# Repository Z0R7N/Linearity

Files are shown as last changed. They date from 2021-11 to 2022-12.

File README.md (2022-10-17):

# Linearity
 check linearity for device with arduino, excel and VBA
 проверка линейности с ардуино и надстройкой к екселю на VBA

panel

The add-on via the COM port, using the API written by me, sends commands to the arduino to turn the device,
reads data on the COM port from the multimeter and saves it to a table.

Надстройка для excel по COM-порту посылает команды в ардуино, с помощью API написанным мной, для поворота прибора, 
считывает данные по другому COM-порту с мультиметра и сохраняет в таблицу.

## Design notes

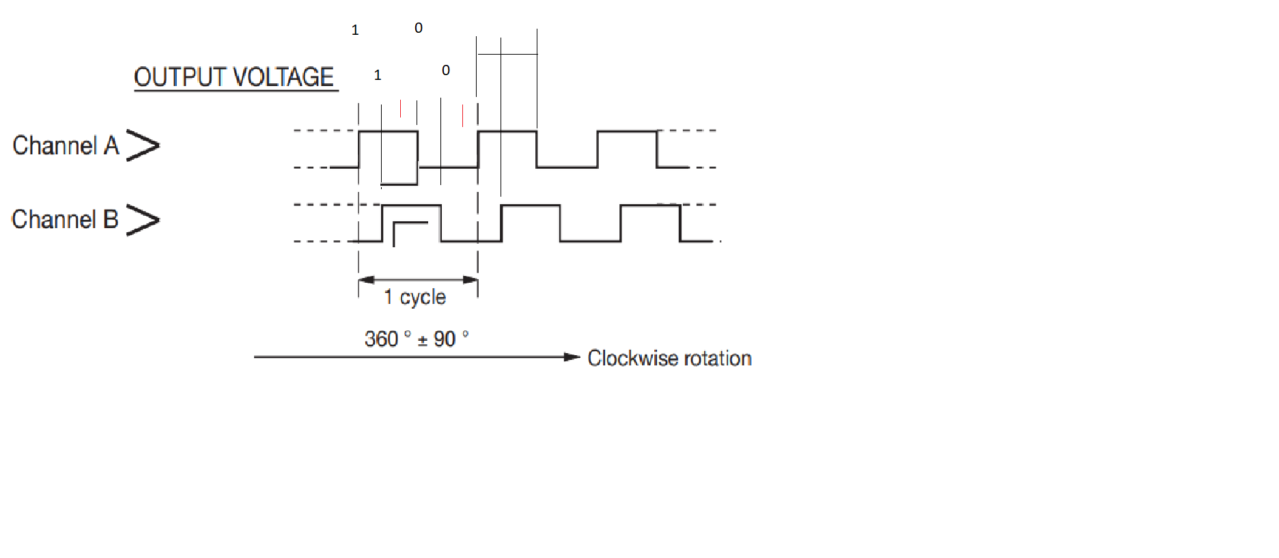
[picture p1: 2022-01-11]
assets/encoder.png

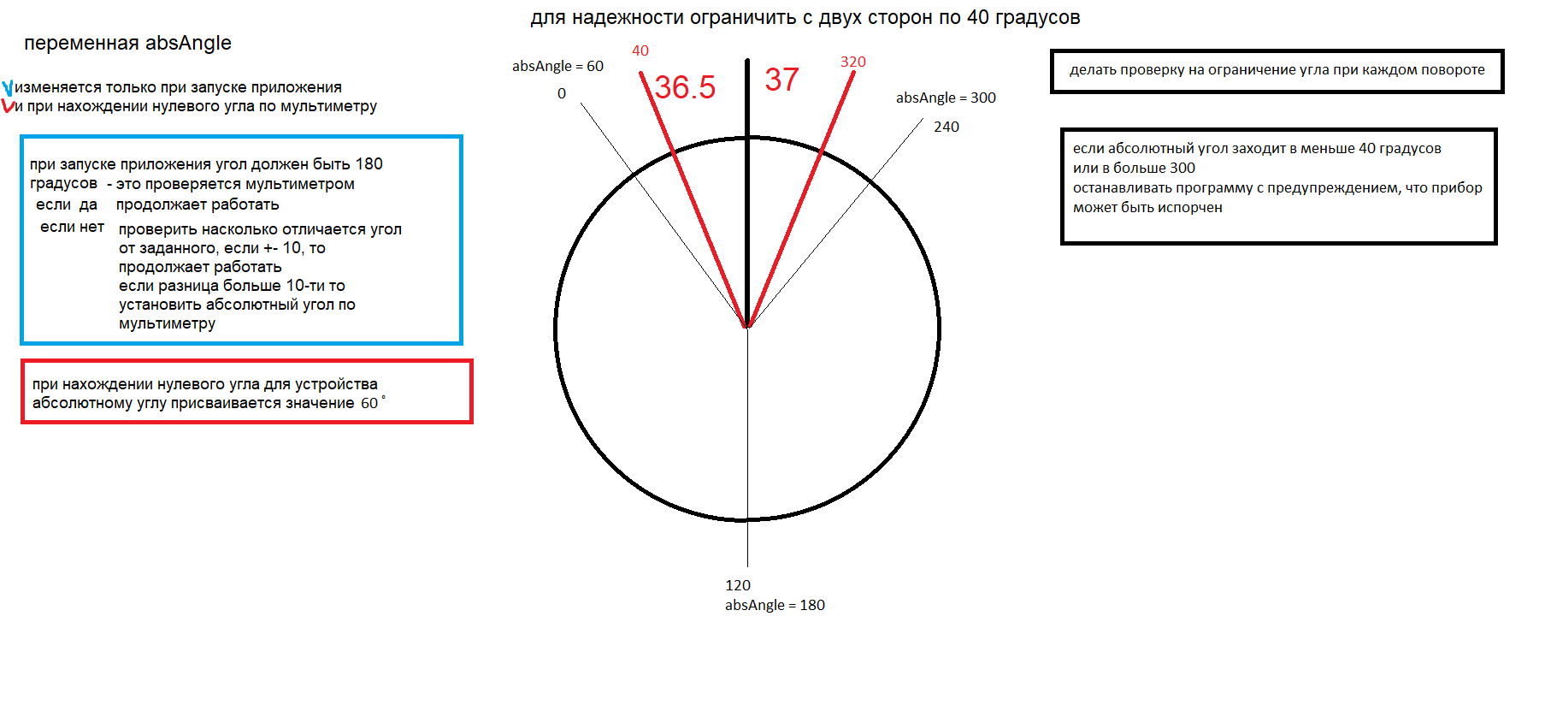
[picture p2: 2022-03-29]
assets/блокировка поворота в сторону упора.png

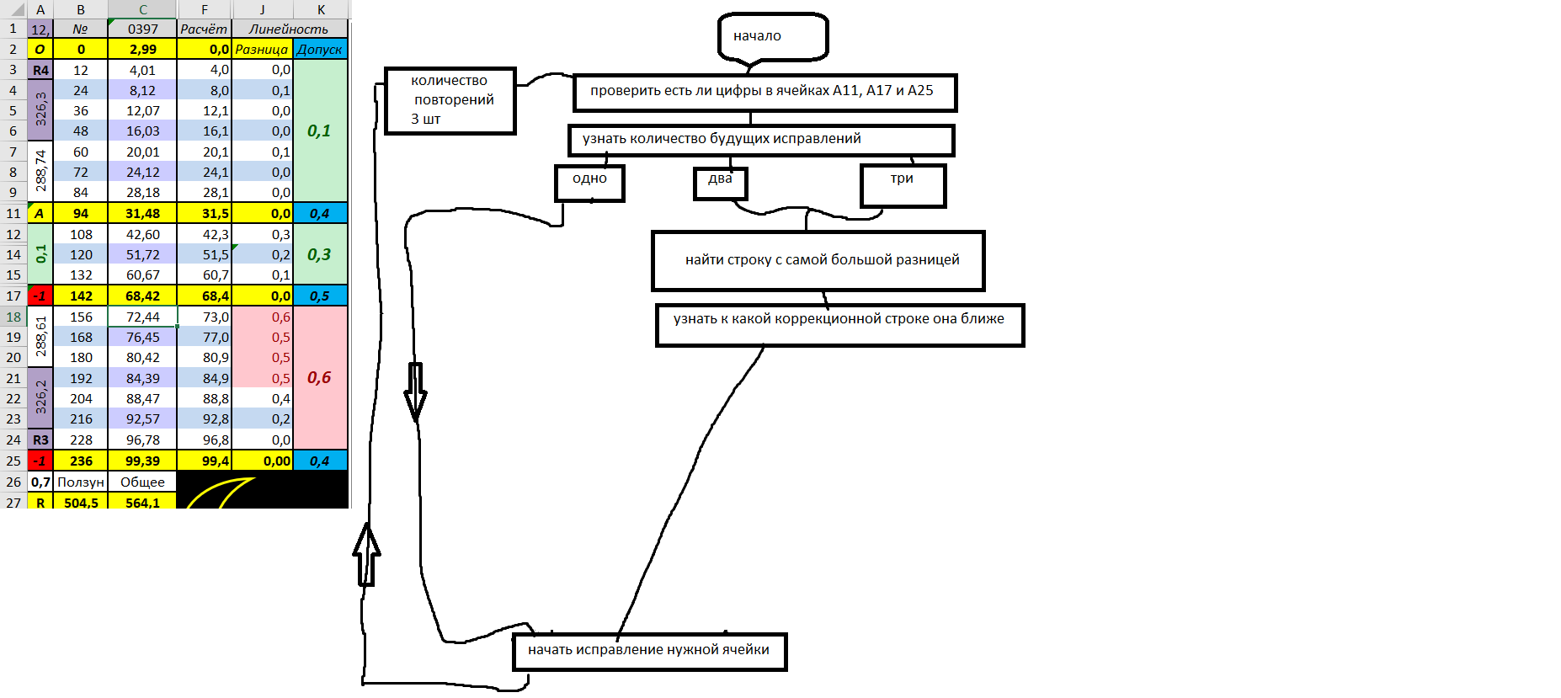
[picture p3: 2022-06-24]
assets/wrong graph.png

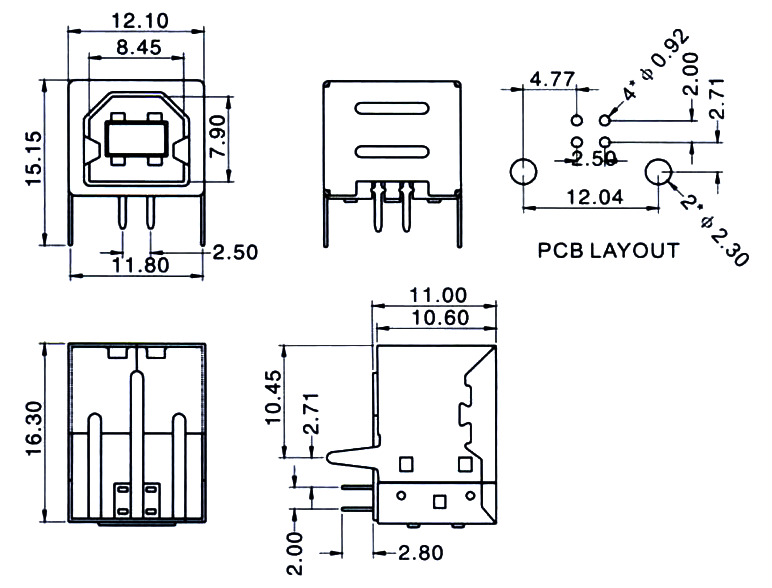
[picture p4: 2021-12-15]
assets/usb B (1).gif

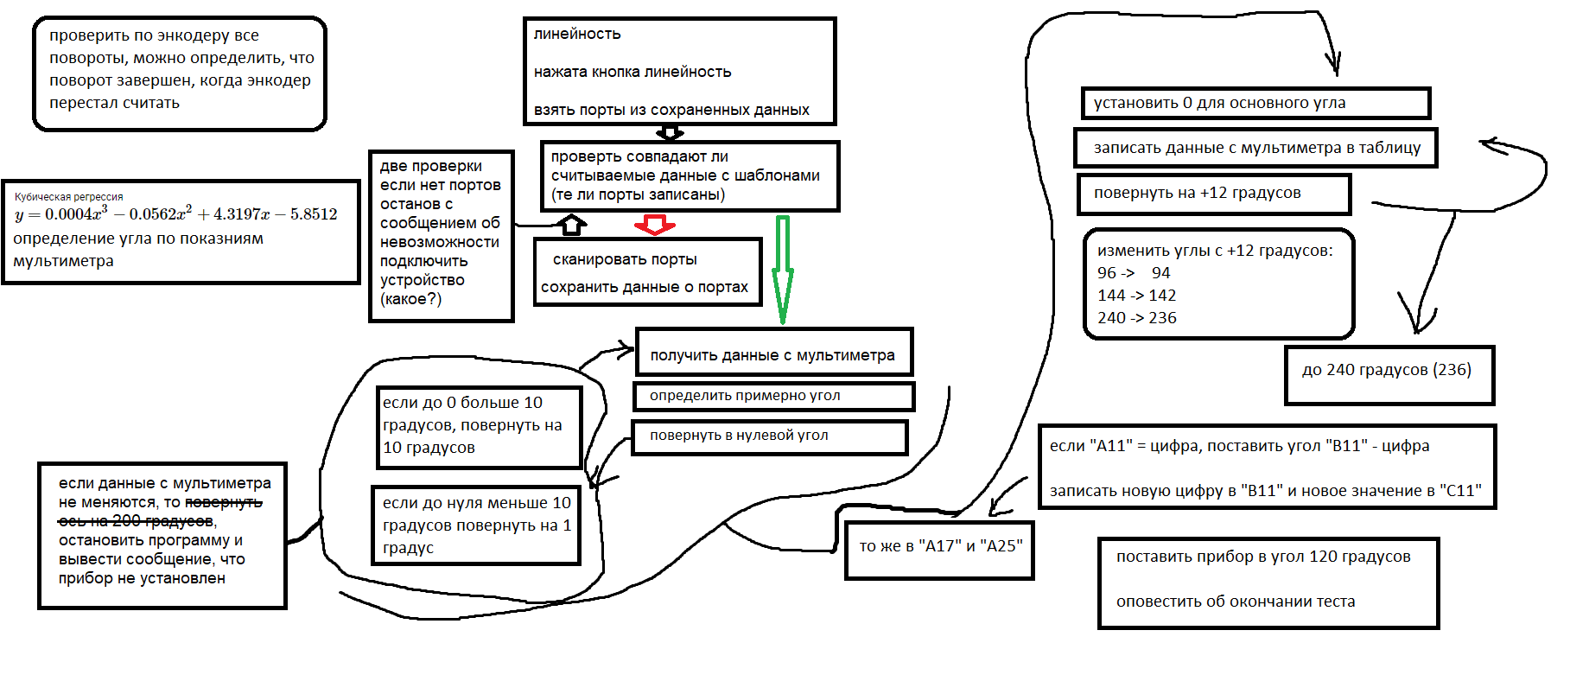
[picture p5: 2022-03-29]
assets/scheme vba linearity.png

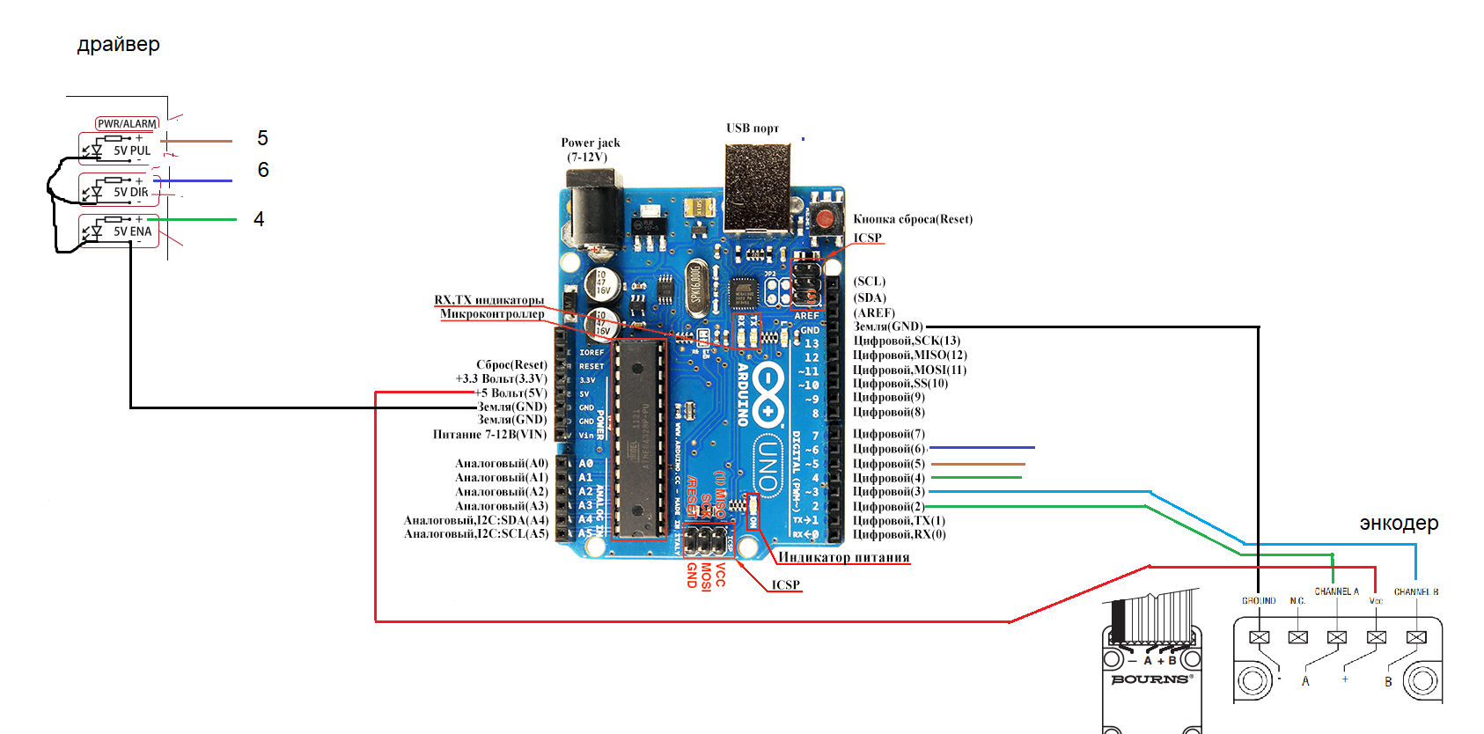
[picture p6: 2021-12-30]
assets/Arduino-Uno.png

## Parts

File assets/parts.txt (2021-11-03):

Шаговый двигатель   	1180 руб
https://www.duxe.ru/catalog/shagovye_dvigateli/dvigateli/shagovyy_dvigatel_57hs76_3004b_dva_vala/

энкодер			+
плата STM STM32H753VI

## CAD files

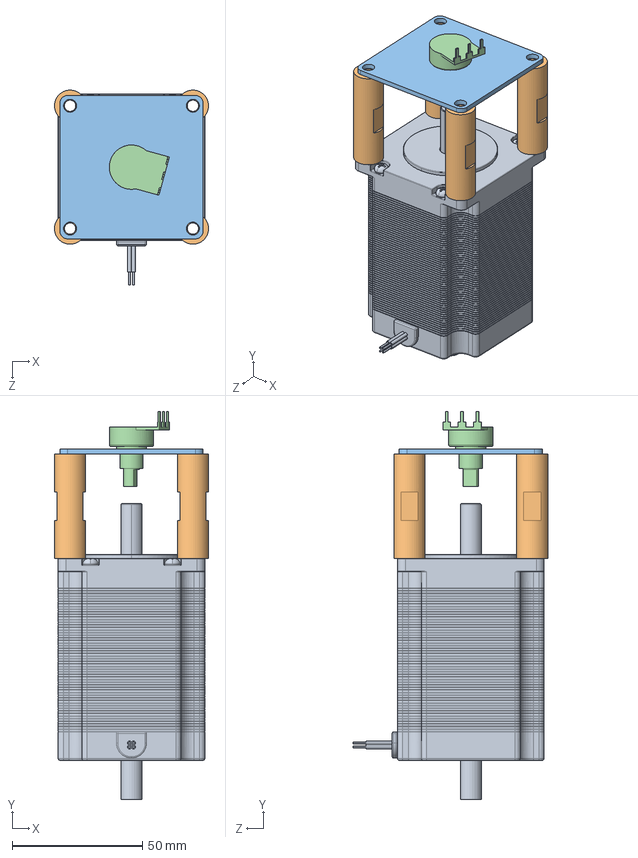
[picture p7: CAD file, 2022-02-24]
3D/Сборка ШД резистор.SLDASM
59.1 x 148.8 x 74.7 mm
Nema 23
стойка резистора x 4
держатель резистора
резистор

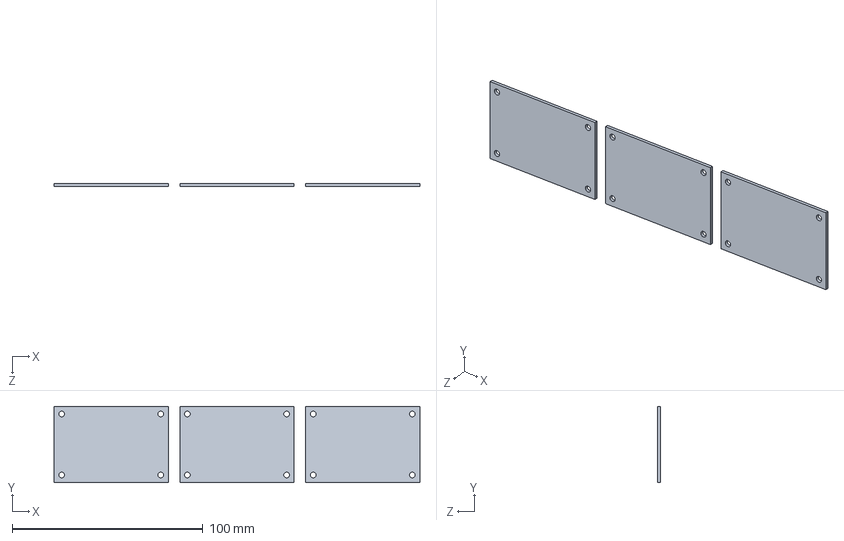
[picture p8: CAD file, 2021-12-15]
3D/обработка/плата заготовка.SLDPRT
192.0 x 40.0 x 1.50 mm

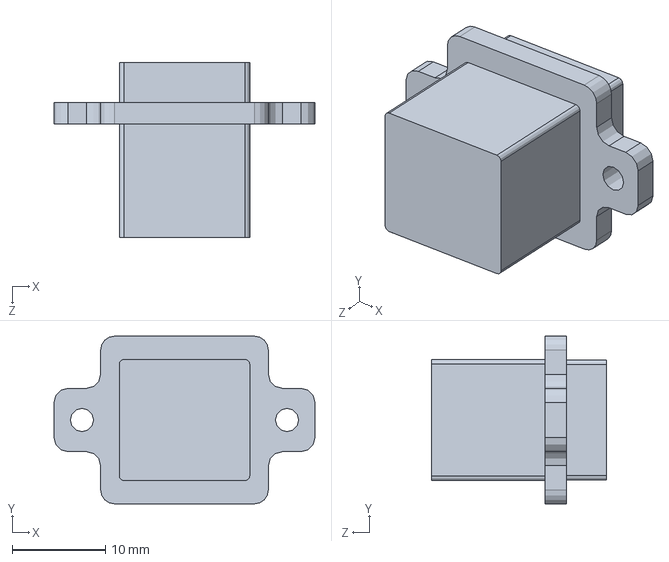
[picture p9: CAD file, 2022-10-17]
3D/разъем USB.SLDPRT
28.0 x 18.0 x 18.8 mm

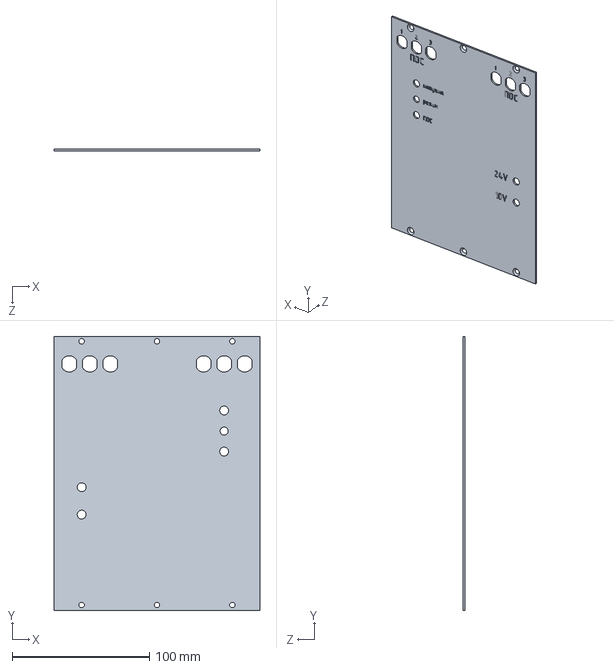
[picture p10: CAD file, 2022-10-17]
3D/стенка перед.SLDPRT
150.0 x 200.0 x 1.50 mm

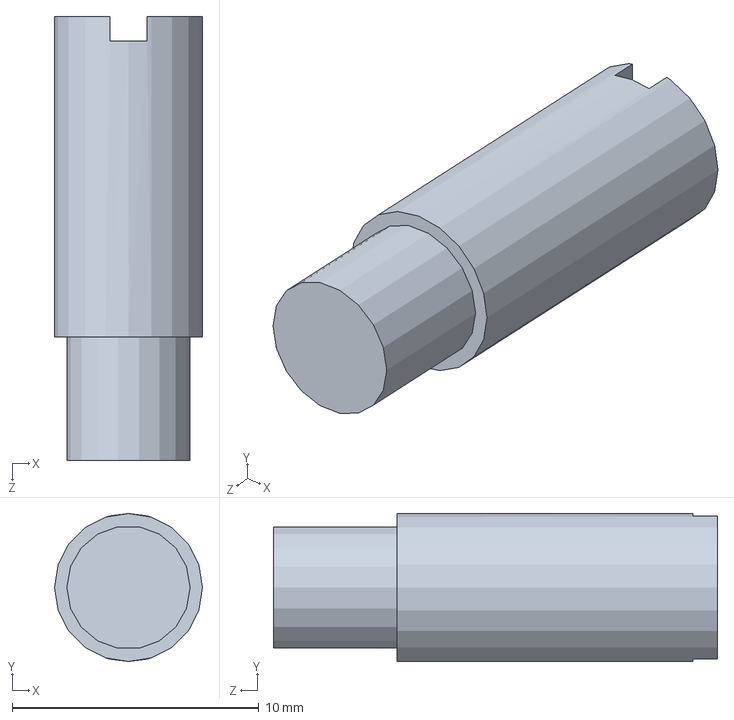
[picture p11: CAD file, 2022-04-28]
3D/штифт эксцентрика.SLDPRT
6.00 x 6.00 x 18.0 mm

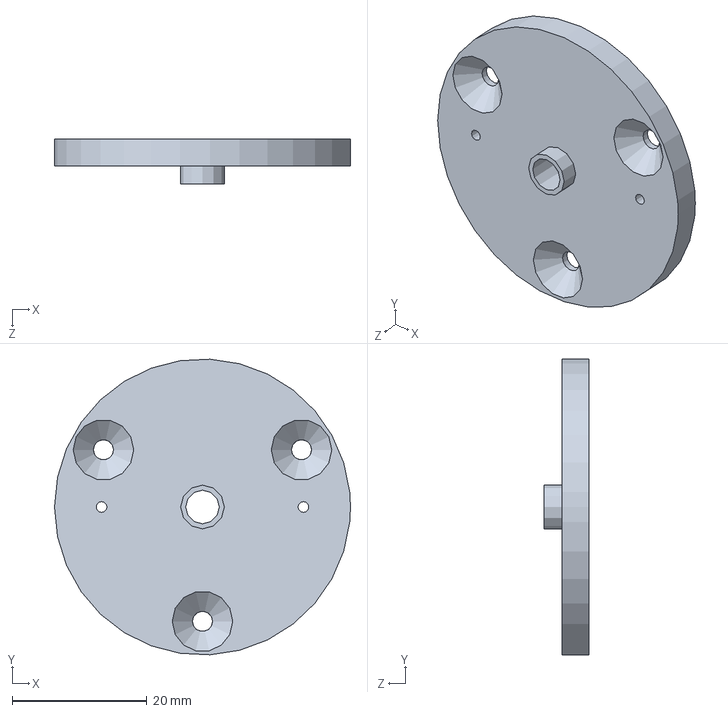
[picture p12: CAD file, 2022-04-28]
3D/крышка верхняя.SLDPRT
44.0 x 43.9 x 6.70 mm

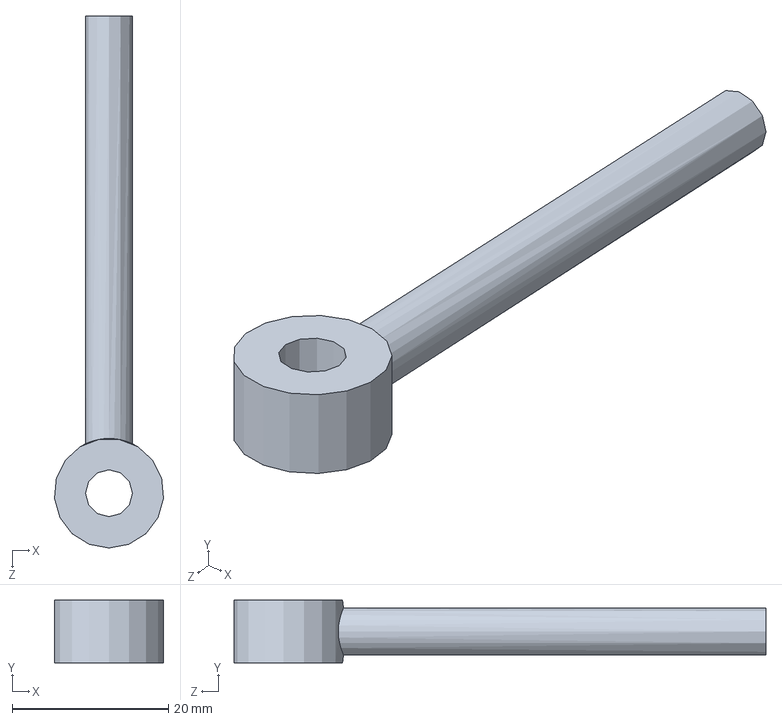
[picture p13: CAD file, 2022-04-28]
3D/винт эксцентрика.SLDPRT
13.9 x 8.00 x 68.0 mm

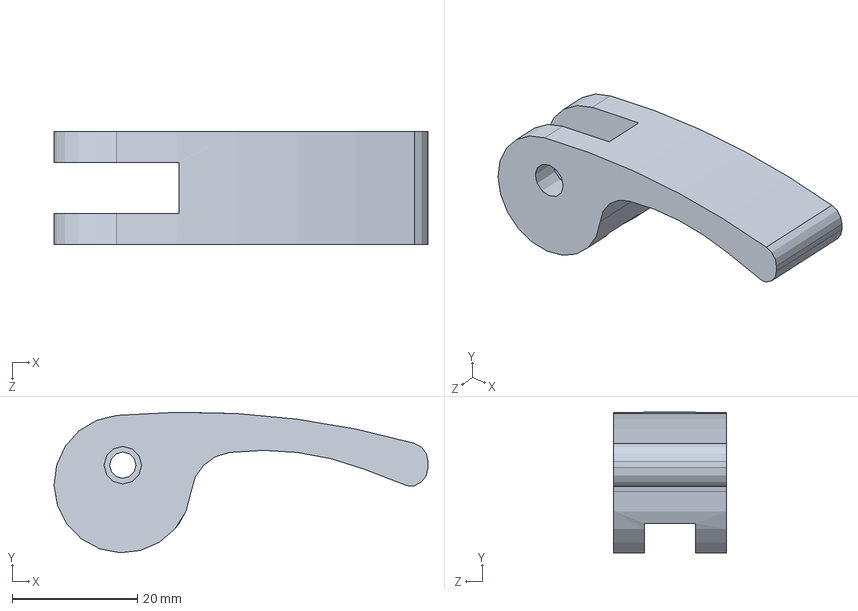
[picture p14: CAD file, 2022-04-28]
3D/эксцентрик.SLDPRT
59.8 x 22.5 x 18.0 mm

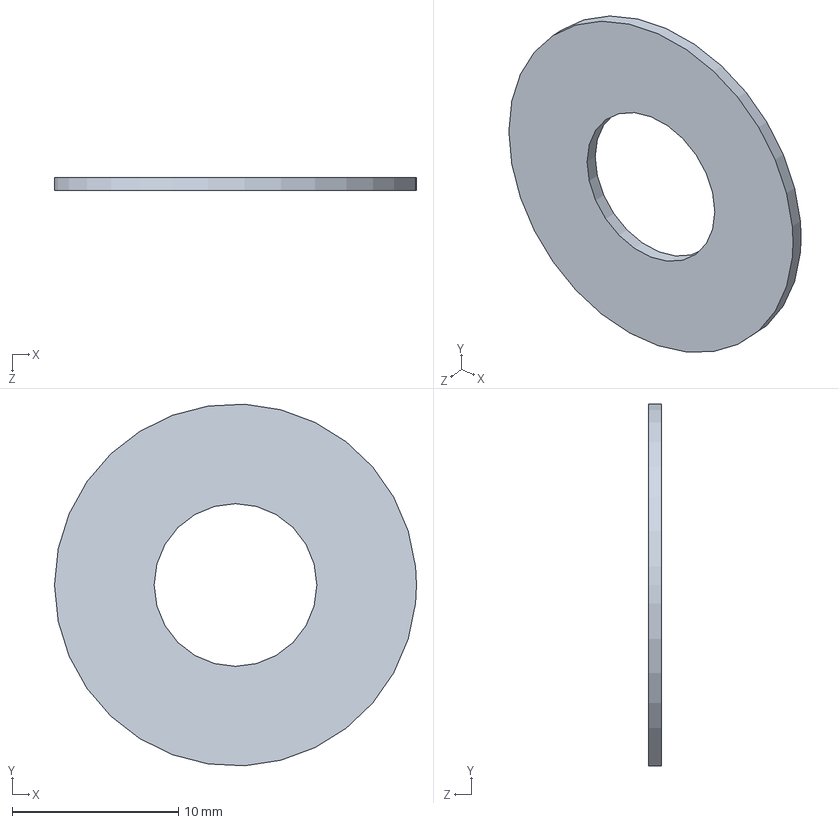
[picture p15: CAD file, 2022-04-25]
3D/контакт.SLDPRT
21.8 x 21.8 x 0.8 mm

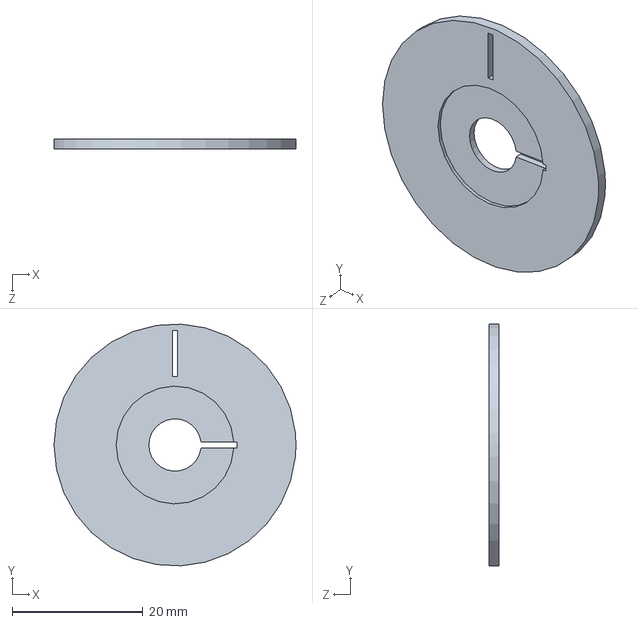
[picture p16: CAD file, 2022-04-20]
3D/диск датчика.SLDPRT
37.0 x 37.0 x 1.50 mm

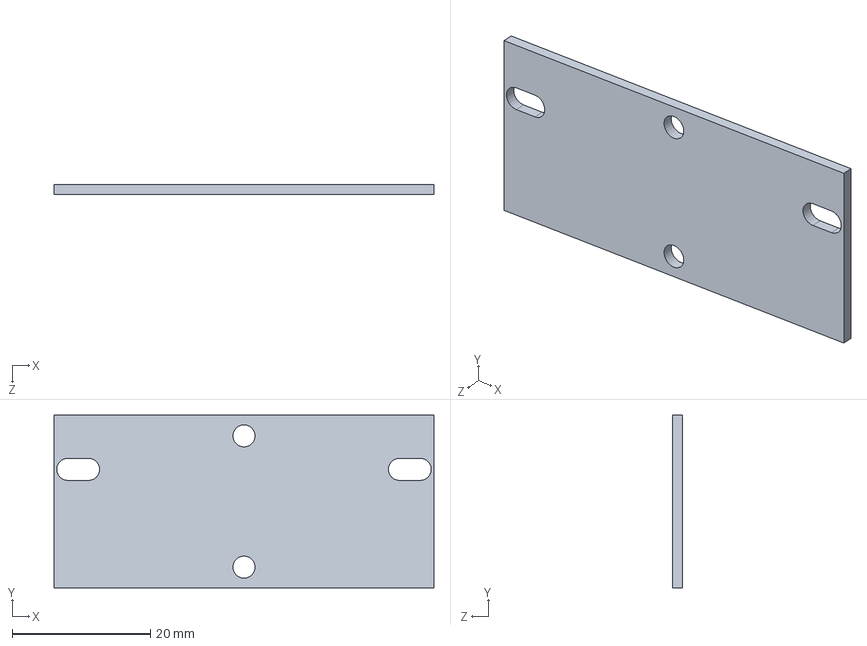
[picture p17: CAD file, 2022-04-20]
3D/держатель датчика.SLDPRT
55.0 x 25.0 x 1.50 mm

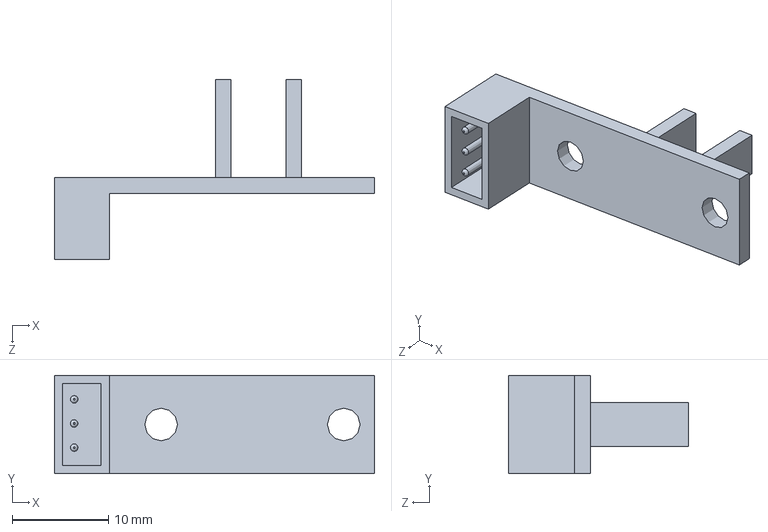
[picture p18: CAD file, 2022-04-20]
3D/датчик.SLDPRT
33.3 x 10.2 x 18.7 mm

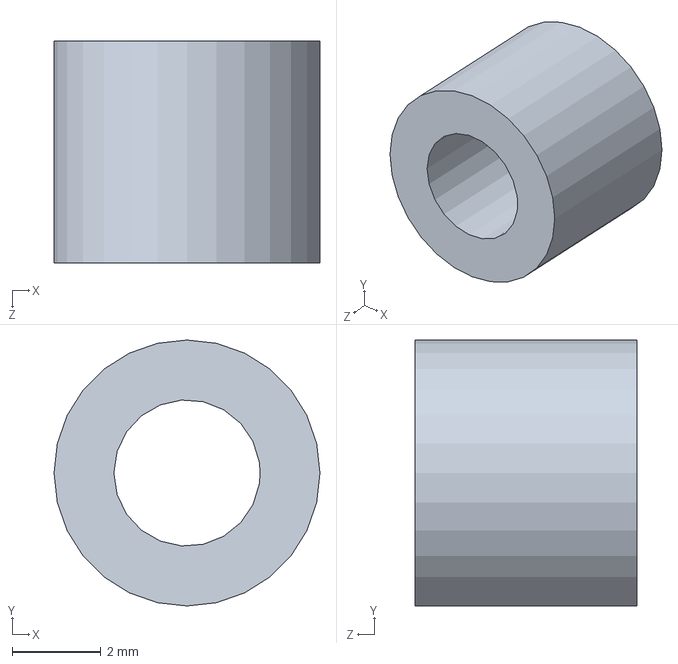
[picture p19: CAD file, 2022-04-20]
3D/датчик стойка.SLDPRT
6.00 x 6.00 x 5.00 mm

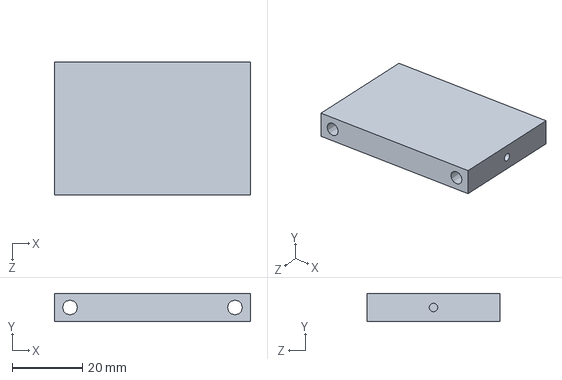
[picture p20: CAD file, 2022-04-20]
3D/стойка.SLDPRT
56.0 x 8.00 x 38.0 mm

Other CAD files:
3D/стенка зад.SLDPRT
3D/прижим.SLDPRT
3D/п_крышка.stp.SLDPRT
3D/изолятор.SLDPRT
3D/Nema 23.SLDPRT
3D/винт 2.SLDPRT
3D/винт опора крышки.SLDPRT
3D/винт.SLDPRT
3D/гайка.SLDPRT
3D/держатель резистора.SLDPRT
3D/держатель энкодера крышка.SLDPRT
3D/держатель энкодера пластина.SLDPRT
3D/держатель энкодера стойка.SLDPRT
3D/драйвер.SLDPRT
3D/муфта.SLDPRT
3D/основание.SLDPRT
3D/ось корпус.SLDPRT
3D/ось.SLDPRT
3D/п_корпус.stp.SLDPRT
3D/п_крышка.stp.x_t
3D/плата для замеров дорожки.SLDPRT
3D/плата для замеров.SLDPRT
3D/плата.SLDPRT
3D/подшипник.SLDPRT
3D/прижим крышки.SLDPRT
3D/резина.SLDPRT
3D/резистор.SLDPRT
3D/стенка бок 2.SLDPRT
3D/стенка бок.SLDPRT
3D/стойка для платы.SLDPRT
3D/стойка крышка.SLDPRT
3D/стойка прижима держатель.SLDPRT
3D/стойка прижима основа.SLDPRT
3D/стойка резистора.SLDPRT
3D/стол.SLDPRT
3D/стопор оси.SLDPRT
3D/фиксатор.SLDPRT
3D/чертежи/винт опора крышки.SLDDRW
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

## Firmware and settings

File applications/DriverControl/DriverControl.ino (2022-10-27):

/*  команды
* - задает нулевую точку
^ - задает основному углу 120 градусов
+ - вращение по часовой стрелке
- - вращение против часовой
/ - вращение на 3'
<> - проверка на установку абсолютного угла
[] - проверка датчика, если 0 то в нулевой точке
# - выводит основной угол
число - угол на который надо поставить ось мотора
ssчисло - установить скорость, от 1 до 9
e - запрос на число энкодера
abs - выводит абсолютный угол оси
hlo - запрос на проверку порта
reset - перезагрузить устройство
! - поиск нулевой позиции, которая равна 120 градусам прибора
b - включить и
f - отключить программное ограничение поворота на углы меньше 40 и больше 320 градусов
*/

#define en2 2
#define en3 3

#define stp 7 // button for enable moving
#define zero 12 // zero point by sensor

#define PUL 5 // impulse for driver
#define DIR 6 // direction for driver
#define ENA 4 // enable

#define angleStep 142.2222222222
#define enCoeff 2.844444444444
#define coefAngl 1422
#define bounc 2						    // value for bounce of rotate
#define setBnc false					// if bounce of rotate is need

int maxPs = 1000;
int minPs = 20;

bool blck = true;					// block for danger rotate (<40 and >320 degrees)
bool goMove = true;					// if block for move (<40 and >320 degrees)
String ser = "";					// string from serial
long mainAngle = -1;				// countong for angle of position steper motor (from 0 to 51200)
long newAngl = 0;					// angle for motor move
long absAngle = -1;					// angle for check zero point equals 180 degrees
int ps = 40;						// delay for pause (20 minimum & 1000 maximum)
long encdr = -1;					// counting encoder
bool cw = true;						// clockwise or counterclockwise rotating
bool rotate = false;				// bool value for checking rotation
bool zeroPoint = false;				// bool value for set sensor point


//declare a function reset with address 0
void(* resetFunc) (void) = 0;

void inter() {
	if(!cw && digitalRead(DIR) == HIGH) {
		encdr++;
	}
	else if (!cw && digitalRead(DIR) == LOW) {
		encdr--;
	}
	else if (cw && digitalRead(DIR) == LOW) {
		encdr++;
	}
	else if (cw && digitalRead(DIR) == HIGH) {
		encdr--;
	}
}

// send pulse to driver
void stepSM(){
	goMove = true;
	if(!cw && digitalRead(DIR) == HIGH) {
		absAngle--;
		mainAngle++;
		if (blockMove()) returnAbsAngle(true, false);
	}
	else if (!cw && digitalRead(DIR) == LOW) {
		absAngle++;
		mainAngle--;
		if (blockMove()) returnAbsAngle(false, true);
	}
	else if (cw && digitalRead(DIR) == LOW) {
		absAngle++;
		mainAngle++;
		if (blockMove()) returnAbsAngle(false, false);
	}
	else if (cw && digitalRead(DIR) == HIGH) {
		absAngle--;
		mainAngle--;
		if (blockMove()) returnAbsAngle(true, true);
	}
	if (goMove) {
		digitalWrite(PUL, HIGH);
		delayMicroseconds(ps);
		digitalWrite(PUL, LOW);
		delayMicroseconds(ps);
		if (absAngle == -1) absAngle = 51199;
		if (absAngle == 51200) absAngle = 0;
	}
}

// change back absAngle
void returnAbsAngle (bool incrA, bool incrM) {
	absAngle = incrA ? ++absAngle : --absAngle;
	mainAngle = incrM ? ++mainAngle : -- mainAngle;
	goMove = false;
}

// change comma to dot
String comma2dot(String com){
	for (int i = 0; i < com.length(); i++) {
		if (char(com[i]) == 44) com[i] = char(46);
	}
	return com;
}

// recognising commands got from port
void getCommand(String com){
	String st = "";
	double num = -1;
	if (com.length() > 0) {
		com = comma2dot(com);
		num = strToDbl(com);
	}
	if (com.length() > 2) st = com.substring(0, 2);
	if (com == "*") {
		mainAngle = 0;
		encdr = 0;
		Serial.println("0");
		Serial.flush();
	}
	else if (com == "zero" || com == "!") {
		searchZero();
		Serial.flush();
	}
	else if (com == "blck" || com == "b") {
		blck = true;
		Serial.println(blck);
		Serial.flush();
	}
	else if (com == "unblck" || com == "f") {
		blck = false;
		Serial.println(blck);
		Serial.flush();
	}
	else if (com == "<>") {
		Serial.println(zeroPoint);
		Serial.flush();
	}
	else if (com == "[]"){
		Serial.println(digitalRead(zero));
		Serial.flush();
	}
	else if (com == "#") {
		double ma = mainAngle >= 0 ? rounding(mainAngle / angleStep) : mainAngle;
		Serial.println(ma);
		Serial.flush();
	}
	else if (com == "abs") {
		double x = absAngle >= 0 ? rounding(absAngle / angleStep) : absAngle;
		Serial.println(x);
		Serial.flush();
	}
	else if (com == "+") {
		digitalWrite(DIR, HIGH);
		cw = false;
		Serial.println(com);
		Serial.flush();
	}
	else if (com == "-") {
		digitalWrite(DIR, LOW);
		cw = true;
		Serial.println(com);
		Serial.flush();
	}
	else if (com == "^") {
		mainAngle = 17066;
		encdr = 341;
		Serial.println(rounding(mainAngle / angleStep));
		// Serial.println(round());
		Serial.flush();
	}
	else if (com == "/") {
		angleSet(mainAngle + 2);
		Serial.flush();
	}
	else if (com == "reset") {
		resetFunc();
	}
	else if (com == "dir") {
		Serial.println(cw ? "-" : "+");
		Serial.flush();
	}
	else if (com == "hlo") {
		Serial.println("hlo");
		Serial.flush();
	}
	else if (com == "e") {
		double enn = encdr >= 0 ? rounding(encdr / enCoeff) : encdr;
		Serial.println(enn);
		Serial.flush();
	}
	else if (com == "help") {
		instruction();
		Serial.flush();
	}
	else if (st == "ss") {
		String spd = com.substring(2);
		ps = speedMotor(spd);
		Serial.println(ps);
		Serial.flush();
	}
	else if (num > 0) {
		angleSet(num);
		Serial.flush();
	}
	else if (com == "0") {
		angleSet(0);
		Serial.flush();
	}
	else {
		// Serial.flush();
	}
}

// rounding for numbers
double rounding(double x){
	x *= 10000;
	double y = round(x);
	x = y / 10000;
	return x;
}

// check for rotation by not motor
void failRotation(){
	if (absAngle == 25600 && !digitalRead(zero)){
		zeroPoint = false;
		absAngle = -1;
		mainAngle = -1;
		encdr = -1;
	}
}

// search point zero
void searchZero(){
	int tmpPs = ps;
	if (absAngle < 0) {
		ps = 5;
	}
	if (!digitalRead(zero)) {
		if (zeroPoint) {
			calculateDir();
		}
		long cnt = 0;
		bool tmpBlck = blck;
		blck = false;
		while (cnt < 700) {
			if (digitalRead(zero)) {
				cnt++;
			} else {
				cnt = 0;
			}
			if(digitalRead(stp)) {
				stepSM();
			}
			else {
				absAngle = -1;
				Serial.println("-1");
				return;
			}
		}
		blck = tmpBlck;
	}
	setValueZero();
	ps = tmpPs;
	Serial.println(rounding(mainAngle / angleStep));
	Serial.flush();
}

// rotate to 180 abs
void calculateDir(){
	double d = absAngle - 25600;
	if (d == 0) return;
	if (d > 0) {
		digitalWrite(DIR, HIGH);
	} else {
		digitalWrite(DIR, LOW);
	}
	
}

// set zero point for value
void setValueZero(){
	if (!zeroPoint) {
		absAngle = 25600;
		mainAngle = 17066;
		encdr = 341;
		zeroPoint = true;
	}
	else {
		if(mainAngle > 37000 || mainAngle < 0) {
			mainAngle = 17066;
			encdr = 341;
		}
		if (absAngle > 25900 || absAngle < 25300) {
			absAngle = 25600;
		}
	}
}


// setting angle
void angleSet(double a){
	long preAngl;						// angle there motor must move before new angle
	double tmp = a * angleStep;
	// Serial.println("========");
	// Serial.println(tmp);
	preAngl = round(tmp);
	// Serial.println(preAngl);
	// Serial.println("--------");
	if (preAngl < mainAngle) {
		newAngl = preAngl - coefAngl;
		setParam();
	}
	if (setBnc) {
		double bndAngl;						// angle there motor must move before new angle
		bndAngl = preAngl + bounc;
		newAngl = bndAngl;
		setParam();
		delay (200);
	}
	newAngl = preAngl;
	setParam();
	Serial.println(rounding(encdr / enCoeff));
	// Serial.print("main: ");
	// Serial.print(rounding(mainAngle / angleStep));
	// Serial.print(" | ");
	// Serial.print(rounding(absAngle / angleStep));
	// Serial.println(" - abs");
	// Serial.println(mainAngle);
	Serial.flush();
}

// instruction
void instruction(){
	Serial.println("команды:");
	Serial.println("* - задает нулевую точку");
	Serial.println("^ - задает основному углу 120 градусов");
	Serial.println("+ - вращение по часовой стрелке");
	Serial.println("- - вращение против часовой");
	Serial.println("/ - вращение на 3'");
	Serial.println("число - угол на который надо поставить ось мотора");
	Serial.println("ssчисло - установить скорость, от 1 до 9");
	Serial.println("e - запрос на число энкодера");
	Serial.println("hlo - запрос на проверку порта");
	Serial.println("<> - проверка на установку абсолютного угла");
	Serial.println("[] - проверка датчика, если 0 то в нулевой точке");
	Serial.println("# - выводит основной угол");
	Serial.println("abs - выводит абсолютный угол оси");
	Serial.println("reset - перезагрузить устройство");
	Serial.println("! - поиск нулевой позиции, которая равна 120 градусам прибора");
	Serial.println("b - включить и");
	Serial.println("f - отключить программное ограничение поворота на углы меньше 40 и больше 320 градусов");
}

// calculating speed
int speedMotor(String s){
	int res = -1;
	double speed = strToDbl(s);
	if (speed > 9 || speed < 1 || s.length() == 0) {
		instruction();
	}
	else{
		speed = 9 - speed;
		speed = speed * 100 / 8;
		speed = 920 * speed / 100;
		res = round(speed);
		res += 80;
	}
	res = res == -1 ? ps : res;
	return res;
}


// setting parameters for moving
void setParam (){
	if (!cw) {
		if (mainAngle < newAngl) {
			digitalWrite(DIR, HIGH);
		}
		else {
			digitalWrite(DIR, LOW);
		}
	}
	else {
		if (mainAngle > newAngl) {
			digitalWrite(DIR, HIGH);
		}
		else {
			digitalWrite(DIR, LOW);
		}
	}
	if (newAngl != mainAngle) move();
}

// move to new angle
void move() {
	double dd = abs(mainAngle - newAngl);
	long n = round(dd);
	// n = n < 0 ? n * -1 : n;
	rotate = true;
	for (long i = 0; i < n; i++) {
		if(digitalRead(stp)) {
			stepSM();
		}
		else {
			break;
		}
	}
	rotate = false;
}

// check for rotating over boundaries
bool blockMove(){
	bool blocker = false;
	if (blck) {
		if (absAngle == 5689 || absAngle < 5689) {
			blocker = true;
		}
		if (absAngle == 45511 || absAngle > 45511) {
			blocker = true;
		}
	}
	return blocker;
}

// converter string to double
double strToDbl(String s){
	double nu = 0;
	int div = 10;
	bool dot = true;
	double res = 0;
	for (int i = 0; i < s.length() - 1; i++) {
		char x = s[i];
		if (x == '.' || x == ','){
			dot = false;
			continue;
		}
		nu = x - '0';
		if (dot) {
			res *= 10;
		} else {
			nu /= div; 
			div *= 10;
		}
		res += nu;
	}
	return res;
}

void setup() {
	pinMode(PC13, OUTPUT);
	digitalWrite(PC13, 0);
	delay(3000);
	digitalWrite(PC13, 1);
	delay(300);
	digitalWrite(PC13, 0);
	delay(2000);
	digitalWrite(PC13, 1);
	delay(200);
	digitalWrite(PC13, 0);
	delay(1000);
	digitalWrite(PC13, 1);
	delay(100);
	digitalWrite(PC13, 0);
	delay(100);
	digitalWrite(PC13, 1);
	delay(100);
	Serial.begin(115200);
	pinMode(PUL, OUTPUT);
	pinMode(DIR, OUTPUT);
	pinMode(ENA, OUTPUT);
	pinMode(en2, INPUT);
	pinMode(en3, INPUT);
	pinMode(stp, INPUT);
	pinMode(zero, INPUT);
	//digitalWrite(ENA, HIGH);
	digitalWrite(ENA, LOW);
	// digitalWrite(DIR, HIGH);
	digitalWrite(DIR, LOW);
	if (digitalRead(zero)) {
		setValueZero();
	}
	attachInterrupt (0, inter, CHANGE);
	attachInterrupt (1, inter, CHANGE);
}

// the loop function runs over and over again forever
void loop() {
	if (Serial.available() > 0){
		ser = "";
		char sr = Serial.read();
		while (int(sr) != -1){// && int(sr) != -1 && int(sr) != 13){
			if (int(sr) != 10 && int(sr) != 13){
				ser += sr;
				Serial.print("read serial: ");
				Serial.println(ser);
			}
			delay(5);
			sr = Serial.read();
		// Serial.println("start loop");
		}
	}
	else {
		if (ser != ""){
			ser.trim();
			failRotation();
			getCommand(ser);
			ser = "";
		}
	}
}

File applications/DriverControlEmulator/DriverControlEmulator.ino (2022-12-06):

/*  команды
* - задает нулевую точку
+ - вращение по часовой стрелке
- - вращение против часовой
/ - вращение на 3'
число - угол на который надо поставить ось мотора
ssчисло - установить скорость, от 1 до 9
saчисло - установить ускорение от 1 до 9
e - запрос на число энкодера
hlo - запрос на проверку порта
reset - перезагрузить устройство
*/

#define en2 2
#define en3 3

#define PUL 5 // impulse for driver
#define DIR 6 // direction for driver
#define ENA 4 // enable

int maxPs = 1000;
int minPs = 80;

String ser = "";					// string from serial
long mainAngle = 0;					// countong for angle of position steper motor (from 0 to 51200)
long newAngl = 0;					// angle for motor move
long preAngl;						// angle there motor must move before new angle
int acc = 5;						// acceleration motor speed
int ps = 150;						// delay for pause (80 minimum & 1000 maximum)
long encdr = 0;						// counting encoder
double angleStep = 142.2222222222;	// coefficient for convert microstep to angle
double enCoeff = 2.844444444444;	// coefficient for convert encoder to angle
bool cw = false;					// clockwise or counterclockwise rotating
int coefAngl = 800;					// coefficient for pre angle
bool rotate = false;				// bool value for checking rotation


//declare a function reset with address 0
void(* resetFunc) (void) = 0;

void inter() {
	if(!cw && digitalRead(DIR) == HIGH) {
		encdr++;
		// if (encdr >= newAngl) {
			// Serial.print(go);
//			 Serial.println("lse");
		// }
	}
	else if (!cw && digitalRead(DIR) == LOW) {
		encdr--;
		// if (encdr <= newAngl) {
			// Serial.print(go);
			// Serial.println(" go false");
		// }
	}
	else if (cw && digitalRead(DIR) == LOW) {
		encdr++;
		// if (encdr >= newAngl) {
			// Serial.print(go);
			// Serial.println(" go false");
		// }
	}
	else if (cw && digitalRead(DIR) == HIGH) {
		encdr--;
		// if (encdr <= newAngl) {
			// Serial.print(go);
			// Serial.println(" go false");
		// }
	}
}

// send pulse to driver
void stepSM(){
	digitalWrite(PUL, HIGH);
	delayMicroseconds(ps);
	digitalWrite(PUL, LOW);
	delayMicroseconds(ps);
	if(!cw && digitalRead(DIR) == HIGH) {
		mainAngle++;
	}
	else if (!cw && digitalRead(DIR) == LOW) {
		mainAngle--;
	}
	else if (cw && digitalRead(DIR) == LOW) {
		mainAngle++;
	}
	else if (cw && digitalRead(DIR) == HIGH) {
		mainAngle--;
	}
}

// recognising commands got from port
void getCommand(String com){
	String st = "";
	double num = -1;
	if (com.length() > 0) {
		num = com.toDouble();
		// Serial.println(num);
	}
	if (com.length() > 2) st = com.substring(0, 2);
	if (com == "*") {
		mainAngle = 0;
		encdr = 0;
		Serial.println("0");
		Serial.flush();
	}
	else if (com == "<>") {
		Serial.println(true);
		Serial.flush();
	}
	else if (com == "+") {
		digitalWrite(DIR, HIGH);
		cw = true;
		Serial.println(com);
		Serial.flush();
	}
	else if (com == "-") {
		digitalWrite(DIR, LOW);
		cw = false;
		Serial.println(com);
		Serial.flush();
	}
	else if (com == "/") {
		angleSet(mainAngle + 1);
	}
	else if (com == "reset") {
		resetFunc();
	}
	else if (com == "dir") {
		Serial.println(digitalRead(DIR) ? "+" : "-");
		Serial.flush();
	}
	else if (com == "hlo") {
		Serial.println("hlo");
		Serial.flush();
	}
	else if (com == "e") {
		Serial.println(mainAngle / angleStep);
		Serial.flush();
	}
	else if (st == "ss") {
		String spd = com.substring(2);
		// Serial.println(spd + " get command ss");
		ps = speedMotor(spd);
		// Serial.print("ps ");
		Serial.println(ps);
		Serial.flush();
	}
	else if (st == "sa") {
		String accel = com.substring(2);
		acc = accelerationMotor(accel);
		Serial.println(acc);
		Serial.flush();
	}
	else if (num > 0) {
		angleSet(num);
	}
	else if (com == "0") {
		angleSet(0);
	}
	else {
		// instruction();
		Serial.println("hlo");
		Serial.flush();
	}
}

// setting angle
void angleSet(double a){
	double tmp = a * angleStep;
	preAngl = round(tmp);
	newAngl = preAngl - coefAngl;
	// Serial.println("pre and new angles");
	// Serial.print(preAngl);
	// Serial.print("        ");
	// Serial.println(newAngl);
	if (preAngl < mainAngle) {
		int tmpAcc = acc;
		acc = 1;
		setParam();
		acc = tmpAcc;
	}
	newAngl = preAngl;
	setParam();
	//Serial.println(round(encdr / enCoeff));
	Serial.println(a);
}

// instruction
void instruction(){
	Serial.println("команды");
	Serial.println("* - задает нулевую точку");
	Serial.println("+ - вращение по часовой стрелке");
	Serial.println("- - вращение против часовой");
	Serial.println("/ - вращение на 3'");
	Serial.println("число - угол на который надо поставить ось мотора");
	Serial.println("ssчисло - установить скорость, от 1 до 9");
	Serial.println("saчисло - установить ускорение от 1 до 9");
	Serial.println("e - запрос на число энкодера");
	Serial.println("hlo - запрос на проверку порта");
}

// calculating speed
int speedMotor(String s){
	int res = -1;
	double speed = s.toDouble();
	if (speed > 9 || speed < 1 || s.length() == 0) {
		instruction();
	}
	else{
		// Serial.print("calculate speed ");
		// Serial.println(speed);
		speed = 9 - speed;
		speed = speed * 100 / 8;
		speed = 920 * speed / 100;
		res = round(speed);
		res += 80;
	}
	// Serial.println(res + " - calcul speed res = ");
	// Serial.println(s + " string coming");
	res = res == -1 ? ps : res;
	return res;
}

// calculating acceleration
int accelerationMotor(String a){
	int res = -1;
	int acceleration = a.toInt();
	if (acceleration > 9 || acceleration < 1 || a.length() == 0) {
		instruction();
	}
	else {
		res = acceleration;
	}
	res = res == -1 ? acc : res;
	return res;
}

// setting parameters for moving
void setParam (){
	if (!cw) {
		if (mainAngle < newAngl) {
			digitalWrite(DIR, HIGH);
		}
		else {
			digitalWrite(DIR, LOW);
		}
	}
	else {
		if (mainAngle > newAngl) {
			digitalWrite(DIR, HIGH);
		}
		else {
			digitalWrite(DIR, LOW);
		}
	}
	// Serial.println(go);
	if (newAngl != mainAngle) move();
}

// move to new angle
void move() {
	long n = mainAngle - newAngl;
	n = n < 0 ? n * -1 : n;
	rotate = true;
	// Serial.println("main  and  new  Angles");
	// Serial.print(mainAngle);
	// Serial.print("steps to move = ");
	// Serial.println(n);
	for (int i = 0; i < n; i++) {
		stepSM();
	}
	rotate = false;
	// Serial.print("угол = ");
	// Serial.println(newAngl);
	// Serial.print("encoder = ");
	// Serial.println(encdr);
	// Serial.println();
}

void setup() {
  pinMode(PUL, OUTPUT);
  pinMode(DIR, OUTPUT);
  pinMode(ENA, OUTPUT);
  pinMode(en2, INPUT);
  pinMode(en3, INPUT);
  //digitalWrite(ENA, HIGH);
  digitalWrite(ENA, LOW);
  // digitalWrite(DIR, HIGH);
  digitalWrite(DIR, LOW);
  Serial.begin(115200);
  //Serial.println("hlo");
  attachInterrupt (0, inter, CHANGE);
  attachInterrupt (1, inter, CHANGE);
}
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

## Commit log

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2021-12-15 add detail processing
    [Nema 23.SLDPRT, винт.SLDPRT, драйвер.SLDPRT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]
2021-12-29 change 3d models
    [Nema 23.SLDPRT, держатель энкодера крышка.SLDPRT, держатель энкодера пластина.SLDPRT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]
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2022-01-13 add backlash compensation
2022-01-17 add xlsx files
    [_3д_1_Ц.xlsx, _LPT10_3.xlsx]
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2022-01-21 add block scheme
    [testVBA.xlsm]
2022-01-23 add emulator multimetr for arduino
    [testVBA.xlsm]
2022-01-24 update method check ports
    [testVBA.xlsm]
2022-01-24 update DriverStep
    [testVBA.xlsm]
2022-01-24 check arduino and vba connect
    [testVBA.xlsm]
2022-01-25 vba is not response if read from arduino
2022-01-26 method for connect arduino is working by debug mode
2022-01-26 connect to two ports is working, LineActive.vb file - sample
2022-01-26 readd new add-in file
    [testVBA.xlsm]
2022-01-27 debug checking port multimetr
    [testLine.xlsm]
2022-01-27 debug serials
    [testLine.xlsm]
2022-01-28 update add-in
    [testLine.xlsm]
2022-01-28 get & put is works
    [testLine.xlsm]
2022-01-28 update LineActiv
    [testLine.xlsm]
2022-01-31 add scan massive ports
    [logLine.xlsx, testLine.xlsm]
2022-02-01 update scan port massive
    [testLine.xlsm]
2022-02-02 error by port of bluetooth
    [testLine.xlsm]
2022-02-02 add wolring for table part
    [testLine.xlsm]
2022-02-03 method scan ports is work
    [testLine.xlsm]
2022-02-03 update working for stol
    [стол.SLDPRT]
2022-02-03 update record to log file
    [logLine.xlsx, testLine.xlsm]
2022-02-04 update scan and check ports in module1
    [logLine.xlsx, testLine.xlsm]
2022-02-06 add method for rotating to zero
    [logLine.xlsx, testLine.xlsm]
2022-02-07 update linearity
    [testLine.xlsm]
2022-02-07 update work for osnova prigima
    [testLine.xlsm]
2022-02-08 debag with encoder response
    [testLine.xlsm]
2022-02-08 method rotate2zero is works
    [testLine.xlsm]
2022-02-10 new file for driver control
    [testLine.xlsm]
2022-02-10 update files driverControlLow and testLine
    [testLine.xlsm]
2022-02-10 update file lineactiv with method exactfit
    [logLine.xlsx, testLine.xlsm]
2022-02-11 fix bug with rotate to zero
    [testLine.xlsm]
2022-02-11 making smallStep is underway
    [testLine.xlsm]
2022-02-14 update method small step
    [testLine.xlsm]
2022-02-14 make method fill table
    [testLine.xlsm]
2022-02-15 add method for check errors
    [testLine.xlsm]
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2022-02-17 add method for rotate to one angle
    [testLine.xlsm]
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2022-02-19 add emulator of multimetr
    for debug app
    [testLine.xlsm]
2022-02-20 add comparison doubles
    [testLine.xlsm]
2022-02-21 update module5 in LineActiv
    [testLine.xlsm]
2022-02-22 debug borders
    [testLine.xlsm]
2022-02-23 add emulator multimetr with resistor
    [testLine.xlsm]
2022-02-24 add holder for resistor
    [Nema 23.SLDPRT, testLine.xlsm, Сборка стенд резистор.SLDASM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]
2022-02-24 get back old version for 3d models
    [Nema 23.SLDPRT, Сборка стенд резистор.SLDASM, винт.SLDPRT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]
2022-02-24 debug app
    [testLine.xlsm, Сборка ШД резистор.SLDASM, держатель резистора.SLDPRT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]
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2022-02-26 app is working for linear
    [testLine.xlsm]
2022-02-26 add stop method in sell of page
    [testLine.xlsm]
2022-02-27 app is working for check linearity
    [testLine.xlsm]
2022-02-28 test app
    [testLine.xlsm]
2022-03-02 update check one angle
    [testLine.xlsm]
2022-03-16 add making fixator
    [гайка.SLDPRT, фиксатор.SLDPRT]
2022-03-29 add fixator making
    [фиксатор.SLDPRT]
2022-04-07 add making PCB
    [плата для замеров дорожки.SLDPRT, плата для замеров.SLDPRT]
2022-04-12 make rotate to one angle
    [винт 2.SLDPRT, винт опора крышки.SLDDRW, винт опора крышки.SLDPRT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]
2022-04-15 change boudrate to multimetr
    [изолятор.SLDPRT, крышка верхняя.SLDPRT, п_крышка.stp.SLDPRT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]
2022-04-20 add make sensor
    [датчик стойка.SLDPRT, датчик.SLDPRT, держатель датчика.SLDPRT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]
2022-04-25 add making contact and search zero point
    [контакт.SLDPRT, п_крышка.stp.x_t]
2022-04-28 add zero point to driver control
    [винт эксцентрика.SLDPRT, крышка верхняя.SLDPRT, штифт эксцентрика.SLDPRT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]
2022-04-29 update check zero point
    [testLine.xlsm]
2022-05-04 add help to driverControl
    [testLine.xlsm]
2022-05-06 test lineActiv
    [testLine.xlsm]
2022-05-11 beta test with resistor
    [testLine.xlsm]
2022-05-13 beta test done success
    [testLine.xlsm]
2022-05-17 add block rotate to DriverControl
    [testLine.xlsm]
2022-05-19 block ready
    [testLine.xlsm]
2022-05-20 implemented check correcting angles
    [_3д_1_Ц.xlsx, testLine.xlsm]
2022-05-20 ready for betatest
    except manual rotate
    [testLine.xlsm]
2022-05-21 fixed bugs in method smallStep
    [DriverControl.ino]
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2022-05-23 after second test and fix round in driver
    [DriverControl.ino]
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2022-05-28 add buttons for check correcting angle
    with message box
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2022-06-02 manual control is implemented
    [testLine.xlsm]
2022-06-04 add checkbox for set zero point manually
    [_3д_1_Ц.xlsx]
2022-06-06 check box set zero point is implemented
    [_3д_1_Ц.xlsx, testLine.xlsm]
2022-06-09 update start up method
    [testLine.xlsm]
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2022-06-11 rename addin to V2
    [_3д_1_Ц.xlsx]
2022-06-14 work at new commands
    [testLine.xlsm]
2022-06-15 change request port for testing
    [testLine.xlsm]
2022-06-16 update line activ V2
    [testLine.xlsm]
2022-06-17 after beta test V2
    and turn off bounce in driver control
2022-06-18 add hot keys
    [_3д_1_Ц.xlsx]
2022-10-17 add 3D objects and method for convert string to double
    [разъем USB.SLDPRT, стенка зад.SLDPRT, стенка перед.SLDPRT]
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
